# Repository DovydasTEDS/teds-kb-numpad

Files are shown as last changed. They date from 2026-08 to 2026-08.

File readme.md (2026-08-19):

# teds-kb-numpad

a numpad / 17-key keypad with per-key rgb lighting, qmk firmware and soon to be added via and possibly signalrgb support!

teds-kb-numpad

## links
[Journal](/JOURNAL.md) [Bill of Materials (markdown)](/bom.md)

## custom cool features
- custom 3d printed case
- cool looking pcb
- hotswap switch sockets
- per-key sk6812 mini-e lighting
- qmk firmware
- via (wip)
- signalrgb (wip)

## pcb design

made completely in kicad, with the TEDS logo and some small text stating the name.

<p float="left">
  
  
  
</p>

## case design

i decided to make the case in 3 parts - the plate, the bottom, and then the top. 
it could be made with just the bottom and plate, but the top helps hide the screws and make it look nice.

<p float="left">
  
  
  
</p>

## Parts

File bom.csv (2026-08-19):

Item | Link | LCSC Part No. | Price | Units | Total Price | Running Total | Notes | Specific No. Neded
PCB |  |  | 12 | 1 | 12 | 12 |  | 1
AliExpress |  |  |  |  |  | 12
Xiao RP2040 | https://www.aliexpress.com/item/1005008233414789.html |  | 8.61 | 1 | 8.61 | 20.61 |  | 1
Hotswap Socket | https://www.aliexpress.com/item/1005007232040760.html |  | 2.11 | 1 | 2.11 | 22.72 |  | 17
Switches | https://www.aliexpress.com/item/1005005930656897.html |  | 15.41 | 1 | 15.41 | 38.13 |  | 17
Stabilisers | https://www.aliexpress.com/item/1005006528731543.html |  | 0 | 1 | 0 | 38.13 | Already Owned | 3
Keycaps | https://www.aliexpress.com/item/1005009162201589.html |  | 10.34 | 1 | 10.34 | 48.47 |  | 17
M3 8m Screw | https://www.aliexpress.com/item/1005007264845313.html |  | 0.81 | 1 | 0.81 | 49.28 |  | 12
M3 Heatset OD4.2 | https://www.aliexpress.com/item/1005003582355741.html |  | 0 | 1 | 0 | 49.28 | Already Owned | 12
LCSC |  |  |  |  | 0 | 49.28
SK6812MINI-E | Already Owned | C5149201 | 0 | 17 | 0 | 49.28 |  | 17
SN74LV1T125DBVR | Already Owned | C473338 | 0 | 1 | 0 | 49.28 |  | 1
1N4148W | Already Owned | C917030 | 0 | 17 | 0 | 49.28 |  | 17
0805W8F3300T5E | 330 Resistor (Already Owned) | C17630 | 0 | 1 | 0 | 49.28 |  | 1
 |  |  |  |  | 0 | 49.28
Case | Self 3d Printed |  | 0 | 1 | 0 | 49.28 |  | 1
 |  |  |  |  | Total: | 49.28

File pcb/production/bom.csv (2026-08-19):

Designator | Footprint | Quantity | Value | LCSC Part #
D1, D10, D11, D12, D13, D14, D15, D16, D17, D2, D3, D4, D5, D6, D7, D8, D9 | D_SOD-123 | 17 | 1N4148W
D19, D20, D21, D22, D23, D24, D25, D26, D27, D28, D29, D30, D31, D32, D33, D34, D35 | LED_MX_6028R | 17 | SK6812MINI-E
MX1, MX10, MX11, MX12, MX13, MX14, MX15, MX16, MX17, MX2, MX3, MX4, MX5, MX6, MX7, MX8, MX9 | SW_MX_HS_CPG151101S11_1u | 17 | MX_SW_HS
R1 | 0805 | 1 | 330R
U2 | SOT-23-5_HandSoldering | 1 | SN74LV1T125DBV

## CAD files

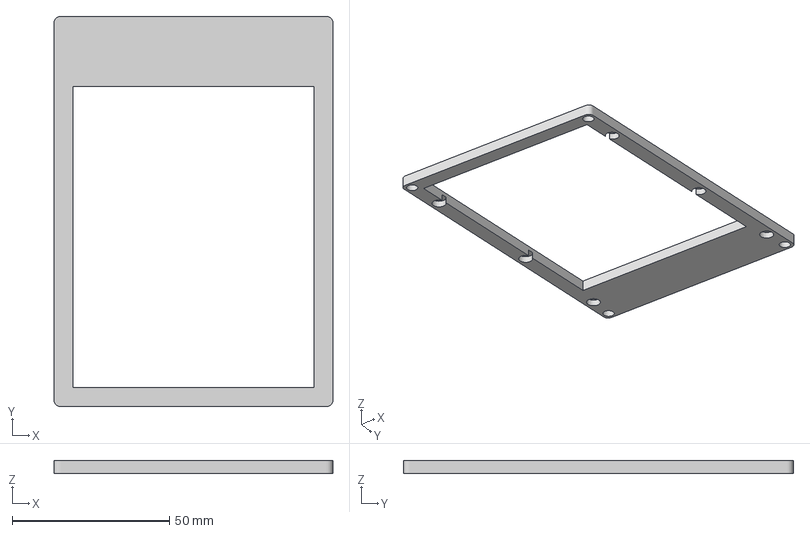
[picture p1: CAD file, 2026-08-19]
cad/3mf/NUMPAD_TOP.3mf
88.6 x 123.9 x 4.00 mm

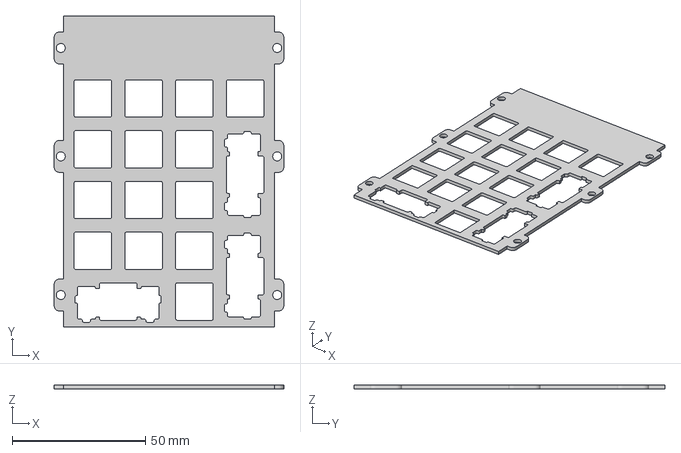
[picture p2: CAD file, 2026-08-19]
prod/NUMPAD_PLATE.3mf
86.2 x 116.7 x 1.50 mm

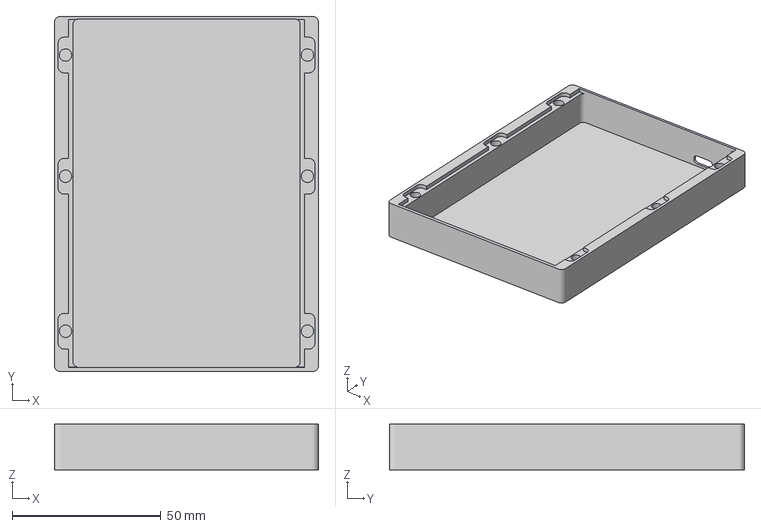
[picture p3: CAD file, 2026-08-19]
cad/3mf/NUMPAD_BOTTOM.3mf
88.6 x 119.3 x 15.4 mm

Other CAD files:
cad/f3d/Bottom.f3d
cad/f3d/Plate.f3d
cad/f3d/Top.f3d

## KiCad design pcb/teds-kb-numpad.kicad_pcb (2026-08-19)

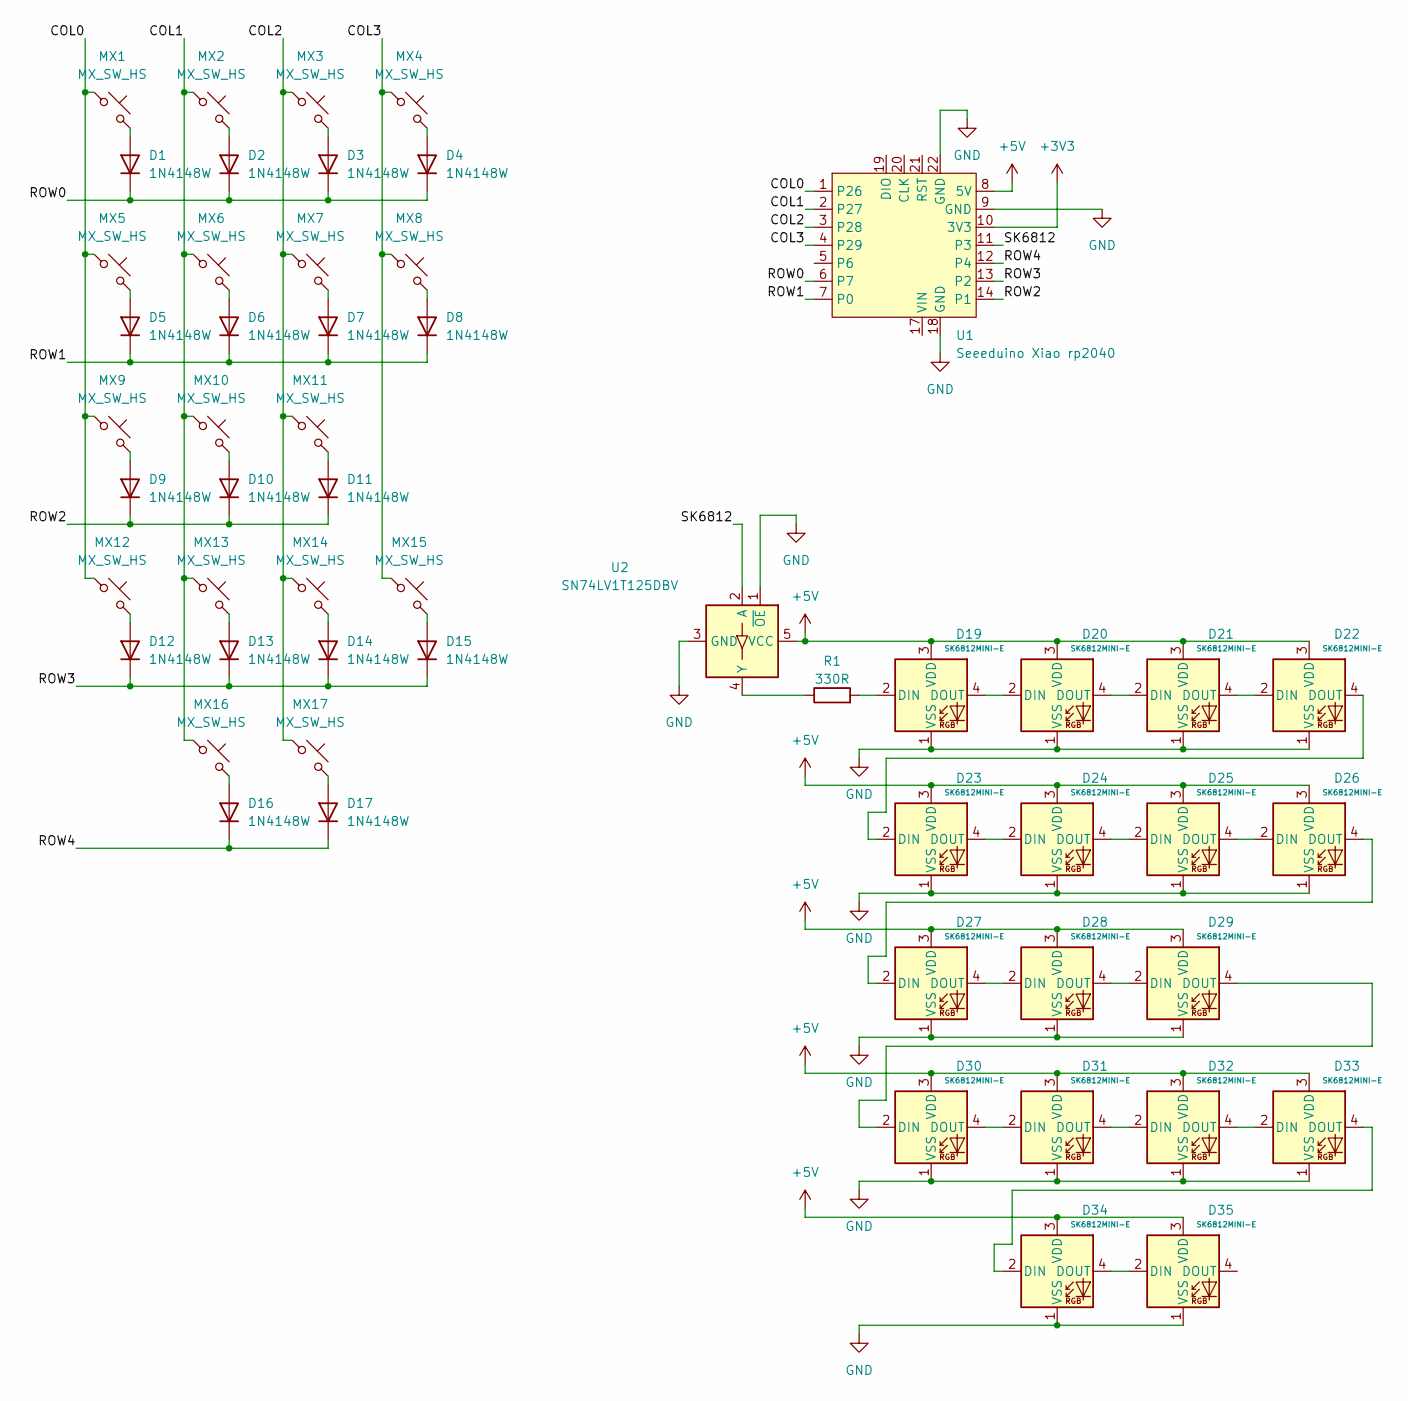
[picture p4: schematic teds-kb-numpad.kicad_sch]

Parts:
D1, D2, D3, D4, D5, D6, D7, D8, D9, D10, D11, D12, D13, D14, D15, D16, D17: 1N4148W; D_SOD-123
D19, D20, D21, D22, D23, D24, D25, D26, D27, D28, D29, D30, D31, D32, D33, D34, D35: SK6812MINI-E; LED_MX_6028R
MX1, MX2, MX3, MX4, MX5, MX6, MX7, MX8, MX9, MX10, MX11, MX12, MX13, MX14, MX15, MX16, MX17: MX_SW_HS; SW_MX_HS_CPG151101S11_1u
R1: 330R; R_0805_2012Metric_Pad1.20x1.40mm_HandSolder
U1: Seeeduino Xiao rp2040; Xiao_rp2040_ACH
U2: SN74LV1T125DBV; SOT-23-5_HandSoldering

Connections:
+3V3: U1.10 (3V3)
+5V: D19.3 (VDD), D20.3 (VDD), D21.3 (VDD), D22.3 (VDD), D23.3 (VDD), D24.3 (VDD), D25.3 (VDD), D26.3 (VDD), D27.3 (VDD), D28.3 (VDD), D29.3 (VDD), D30.3 (VDD), D31.3 (VDD), D32.3 (VDD), D33.3 (VDD), D34.3 (VDD), D35.3 (VDD), U1.8 (5V), U2.5 (VCC)
/COL0: MX1.1, MX5.1, MX9.1, MX12.1, U1.1 (P26)
/COL1: MX2.1, MX6.1, MX10.1, MX13.1, MX16.1, U1.2 (P27)
/COL2: MX3.1, MX7.1, MX11.1, MX14.1, MX17.1, U1.3 (P28)
/COL3: MX4.1, MX8.1, MX15.1, U1.4 (P29)
/ROW0: D1.1 (K), D2.1 (K), D3.1 (K), D4.1 (K), U1.6 (P7)
/ROW1: D5.1 (K), D6.1 (K), D7.1 (K), D8.1 (K), U1.7 (P0)
/ROW2: D9.1 (K), D10.1 (K), D11.1 (K), U1.14 (P1)
/ROW3: D12.1 (K), D13.1 (K), D14.1 (K), D15.1 (K), U1.13 (P2)
/ROW4: D16.1 (K), D17.1 (K), U1.12 (P4)
/SK6812: U1.11 (P3), U2.2 (A)
GND: D19.1 (VSS), D20.1 (VSS), D21.1 (VSS), D22.1 (VSS), D23.1 (VSS), D24.1 (VSS), D25.1 (VSS), D26.1 (VSS), D27.1 (VSS), D28.1 (VSS), D29.1 (VSS), D30.1 (VSS), D31.1 (VSS), D32.1 (VSS), D33.1 (VSS), D34.1 (VSS), D35.1 (VSS), U1.9 (GND), U1.18 (GND), U1.22 (GND), U2.1 (~OE), U2.3 (GND)
unnamed: D1.2 (A), MX1.2
unnamed: D2.2 (A), MX2.2
unnamed: D3.2 (A), MX3.2
unnamed: D4.2 (A), MX4.2
unnamed: D5.2 (A), MX5.2
unnamed: D6.2 (A), MX6.2
unnamed: D7.2 (A), MX7.2
unnamed: D8.2 (A), MX8.2
unnamed: D9.2 (A), MX9.2
unnamed: D10.2 (A), MX10.2
unnamed: D11.2 (A), MX11.2
unnamed: D12.2 (A), MX12.2
unnamed: D13.2 (A), MX13.2
unnamed: D14.2 (A), MX14.2
unnamed: D15.2 (A), MX15.2
unnamed: D16.2 (A), MX16.2
unnamed: D17.2 (A), MX17.2
unnamed: D19.2 (DIN), R1.2
unnamed: D19.4 (DOUT), D20.2 (DIN)
unnamed: D20.4 (DOUT), D21.2 (DIN)
unnamed: D21.4 (DOUT), D22.2 (DIN)
unnamed: D22.4 (DOUT), D23.2 (DIN)
unnamed: D23.4 (DOUT), D24.2 (DIN)
unnamed: D24.4 (DOUT), D25.2 (DIN)
unnamed: D25.4 (DOUT), D26.2 (DIN)
unnamed: D26.4 (DOUT), D27.2 (DIN)
unnamed: D27.4 (DOUT), D28.2 (DIN)
unnamed: D28.4 (DOUT), D29.2 (DIN)
unnamed: D29.4 (DOUT), D30.2 (DIN)
unnamed: D30.4 (DOUT), D31.2 (DIN)
unnamed: D31.4 (DOUT), D32.2 (DIN)
unnamed: D32.4 (DOUT), D33.2 (DIN)
unnamed: D33.4 (DOUT), D34.2 (DIN)
unnamed: D34.4 (DOUT), D35.2 (DIN)
unnamed: R1.1, U2.4 (Y)

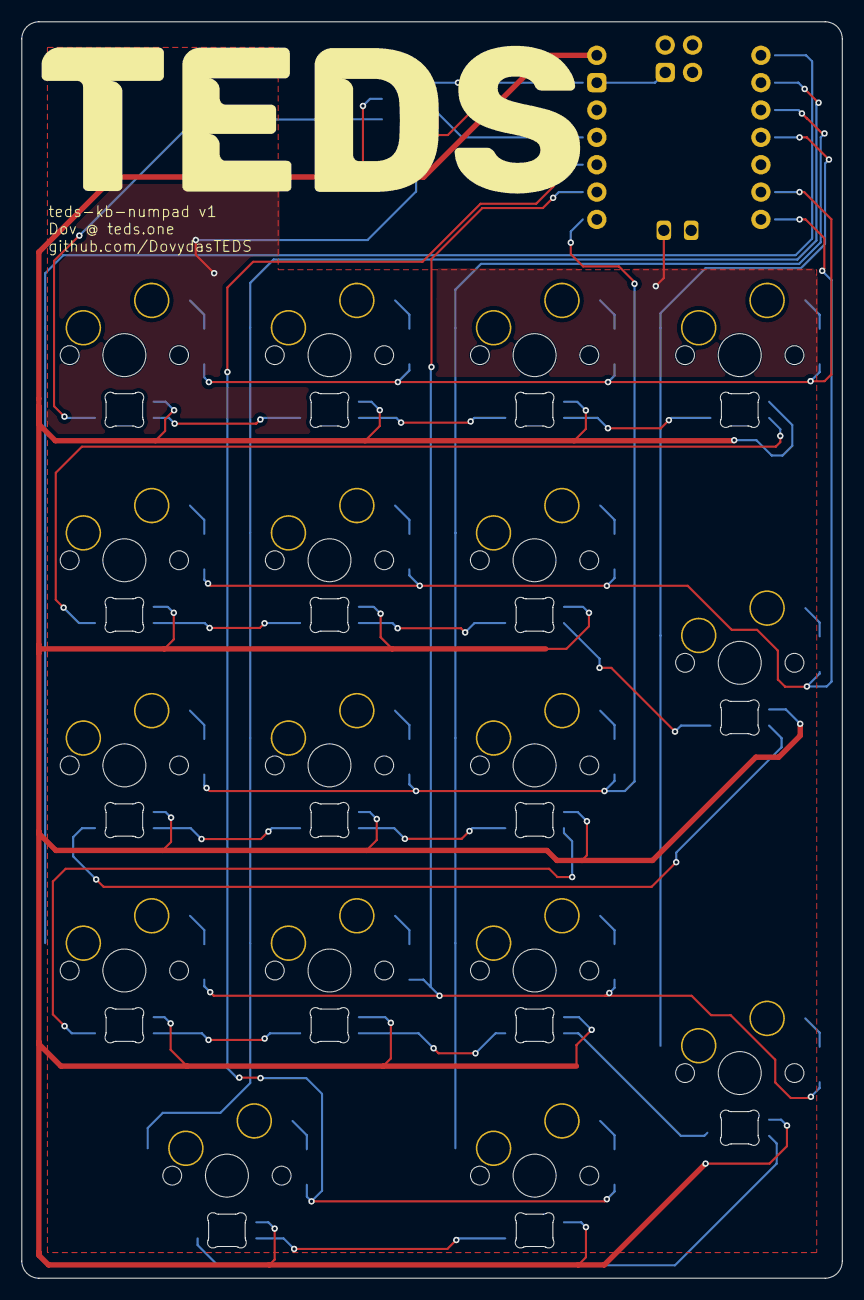
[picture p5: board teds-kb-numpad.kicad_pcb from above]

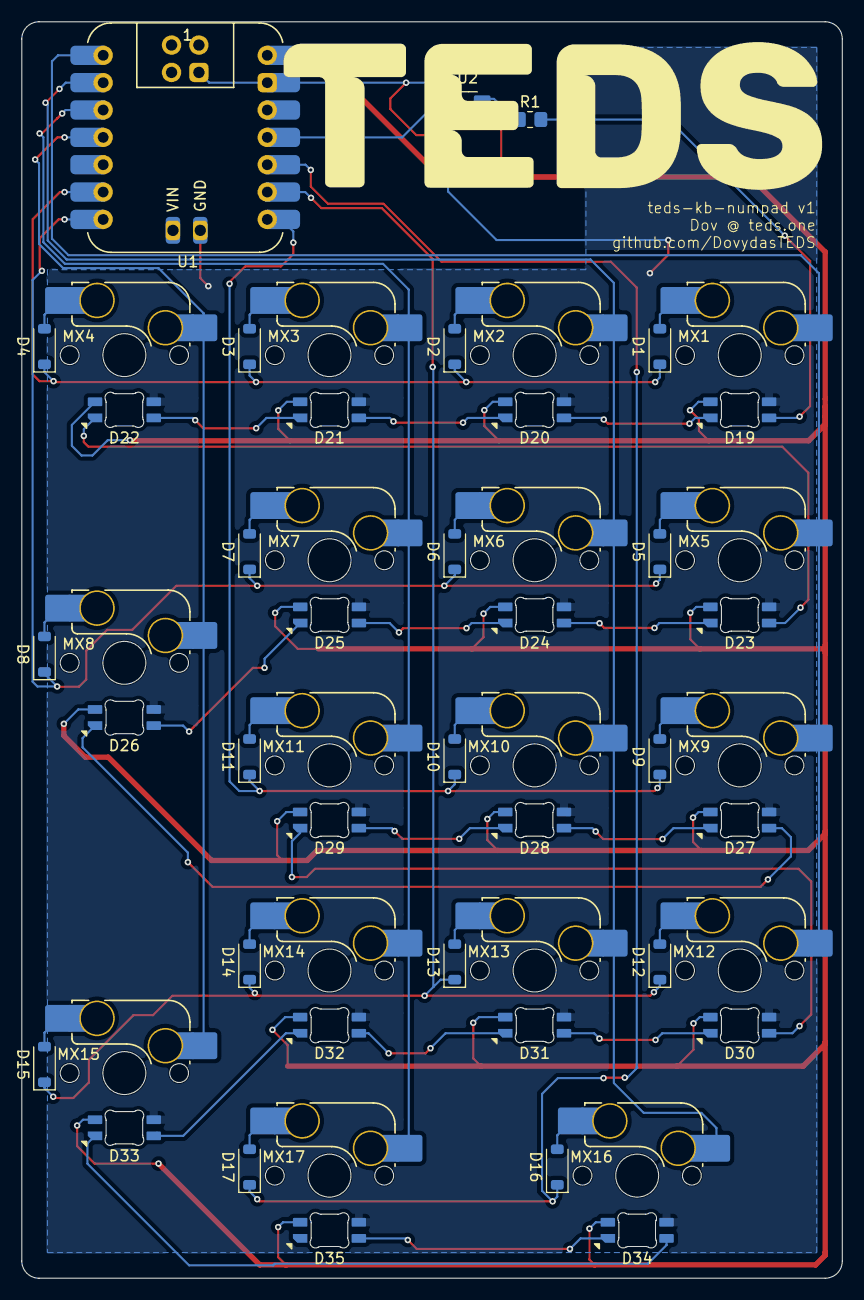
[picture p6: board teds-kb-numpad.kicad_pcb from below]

Board: 2 copper layers, 76.2 x 116.7 mm, 54 parts (54 on the bottom side), 47 nets.

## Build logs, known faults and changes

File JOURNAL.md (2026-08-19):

---
title: "teds-kb-numpad"
github: "your repo"
description: "A small RP2040 powered numpad!"
created_at: "2026-08-18"
---
  
# August 18th:  

I created the numpad matrix, and added an EC11 rotary encoder. I used the MX_SW_HS so that I can add hotswap support if the budget allows.


Hours taken: **1.5**



I then added per-key SK6812MINI-E LEDs as well as a logic shifter so that the signal would be suitable for the LEDs.

Hours taken: **1.5**



I placed all of the switches and diodes. I then connected all the diodes to the switches. After this, I placed all of the SK6812MINI-E LEDs. After placing them, I realised I was missing 1 GPIO pin for the LEDs so I will be removing the rotary encoder.

Hours taken: **2**



I had to rotate everything because I forgot it was meant to be flipped. And then I connected all of the rows and columns together and to the XIAO RP2040.

Hours taken: **1**



Finished the PCB! I had to fix some disconnected items. I then added a ground plane which the thermal reliefs are hopefully enough!
Next steps involve designing the case and writing some basic firmware!

Hours taken: **2.5**

# August 19th:

cad case

I imported the PCB into KiCad. I started of with the case. After making the plate, I then used the assembly and edit in place to design both the bottom and top. I also included a slot for the USBC of the devboard.

Hours taken: **3**

I then made the firmware quickly, just something simple so that it would work properly. I haven't made any extra layers but I will do that later.

Hours taken: **0.5**

Overall hours spent: **12**

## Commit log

2026-08-19 finish pcb
    [teds-kb-numpad.kicad_pcb, teds-kb-numpad.kicad_sch]
2026-08-19 make firmware
    [bom.csv, bom.xlsx, designators.csv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]
